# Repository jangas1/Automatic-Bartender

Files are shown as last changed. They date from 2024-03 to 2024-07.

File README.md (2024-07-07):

## Automatic Bartender

This is a project of an automated bartender with several functions which can be accessed from a menu on an LCD display. It is core function is to detect shot glasses and pour any drink (it has to be mannualy set by putting a tube into it) and count the number of shots poured on each position (it can be reseted at any time in menu postion "Drink counter"). The menu is operated using the encoder by turning it and pressing it at a given position. It has 3 submenues: "Capacity", "Drink counter" and "Pour" (which isn't really a submenu, but a button). "Capacity" submenu lets the user change the capacity of their drinks (with 5 ml step). "Drink counter" counts drink on each position and can reset the counter at any moment. "Pour" starts the automatic bartender and pours drinks on each position.

# Example of its work

<video width="640" height="480" controls>
  <source src="AutomaticBartenderExample.mp4" type="video/mp4">
</video>

If the video of its work is unavailable or doesn't work, use this [link](AutomaticBartenderExample.mp4)

Created by:
Mateusz Jangas
Daniel Niewiadomski

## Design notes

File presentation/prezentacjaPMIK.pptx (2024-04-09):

## Stacja Barmańska

Daniel Niewiadomski i Mateusz Jangas

## Zastosowanie urządzenia/algorytm działania

- Połóż dedykowane dla urządzenia kieliszki na od 1 do 4 dowolnych pozycji
- (opcjonalne) połóż szklanki i ustaw poprzez stronę internetową na których pozycjach się znajdują
- Program zapala diodę gdy dana pozycja jest aktywna
- Ustaw encoderem w menu, znajdującym się na wyświetlaczu, ile mililitrów urządzenie ma polewać
- Uruchom polewanie dowolnego napoju podłączonego do urządzenia
- Ciesz się resztą wieczoru obserwując w menu jaka ilość drinków została polana na każdej pozycji

## Stopień zaawansowania - mechanika

(tu wklej ss z inventora)

## Napotkane problemy i ich rozwiązania

- (Tu Daniel coś wstawia)

## Stopień zaawansowania - oprogramowanie

Designed by PoweredTemplate.com

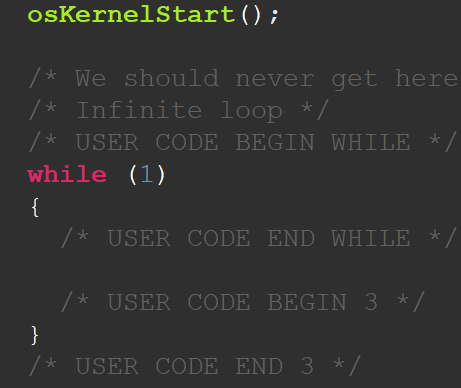
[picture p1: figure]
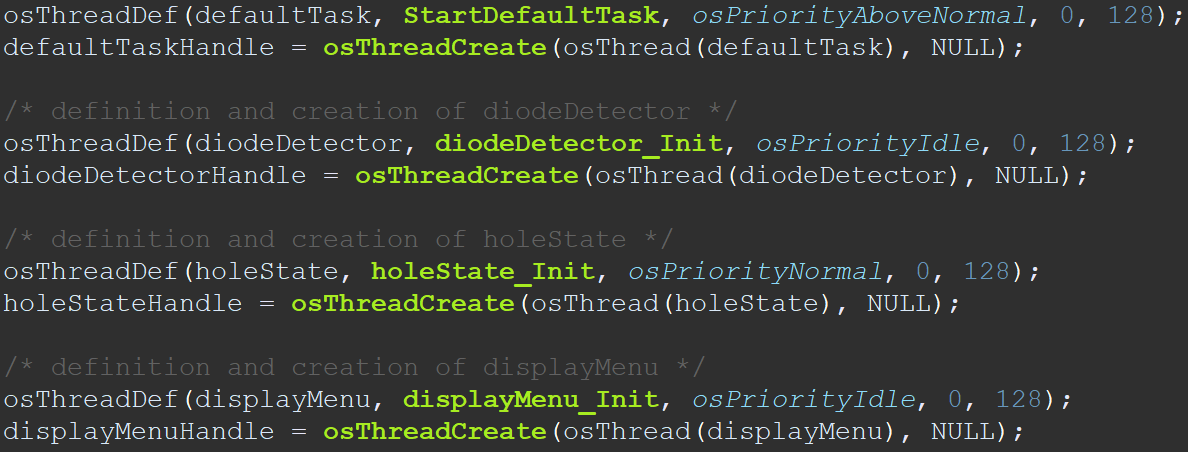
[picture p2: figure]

## Stopień zaawansowania - oprogramowanie

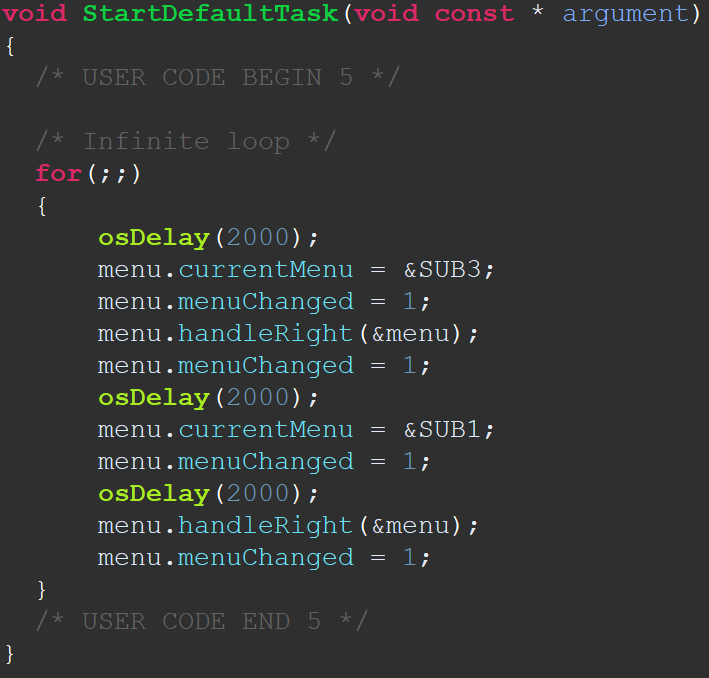
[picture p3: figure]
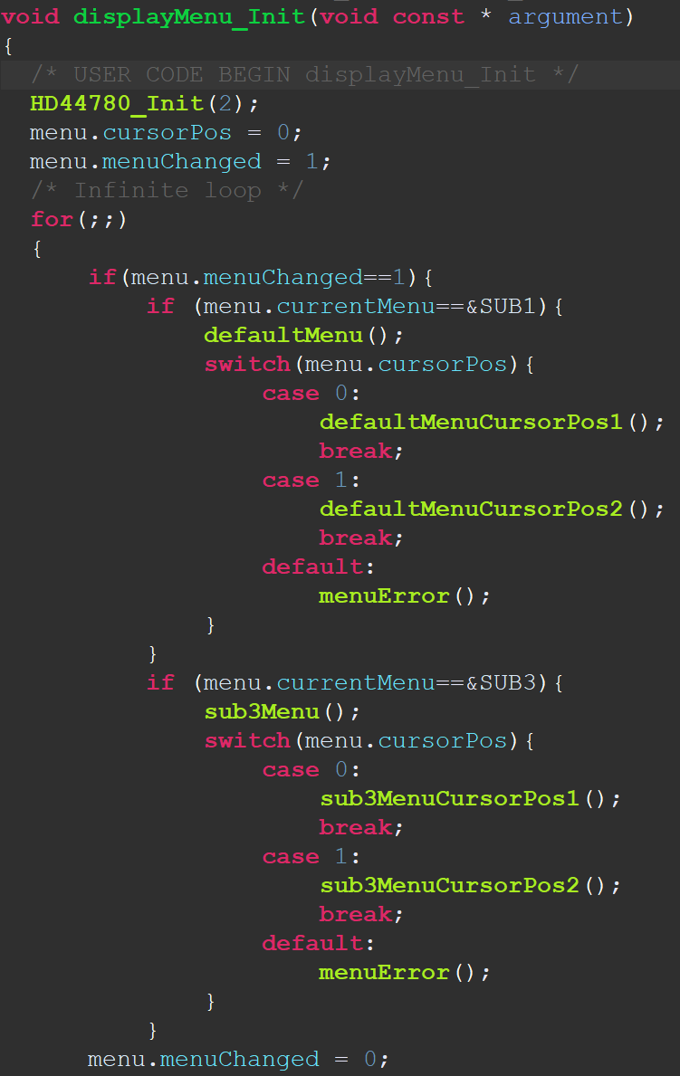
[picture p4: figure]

## Napotkane problemy i ich rozwiązania

- Zbyt lekkie kieliszki – problem z zastosowaniem tensorów czy przycisków do automatycznego wykrywania

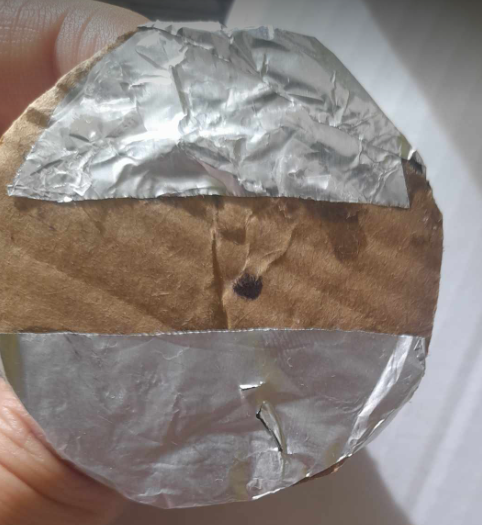
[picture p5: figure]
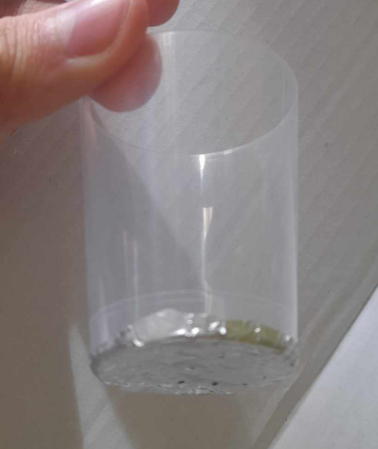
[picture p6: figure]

## Koniec

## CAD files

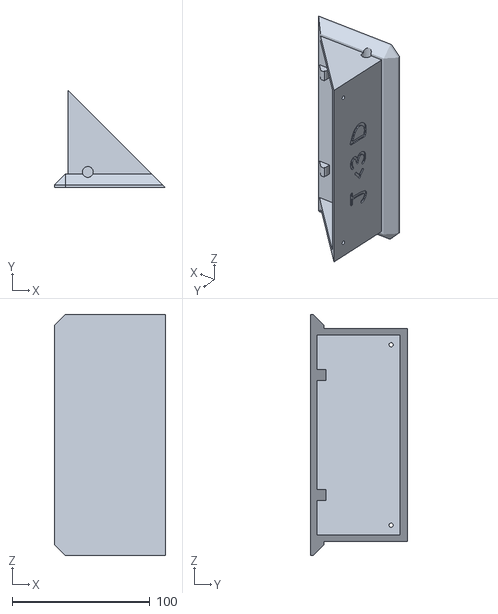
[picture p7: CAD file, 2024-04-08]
mechanical/manuDisplayHolder.stl
80.7 x 70.7 x 175.0

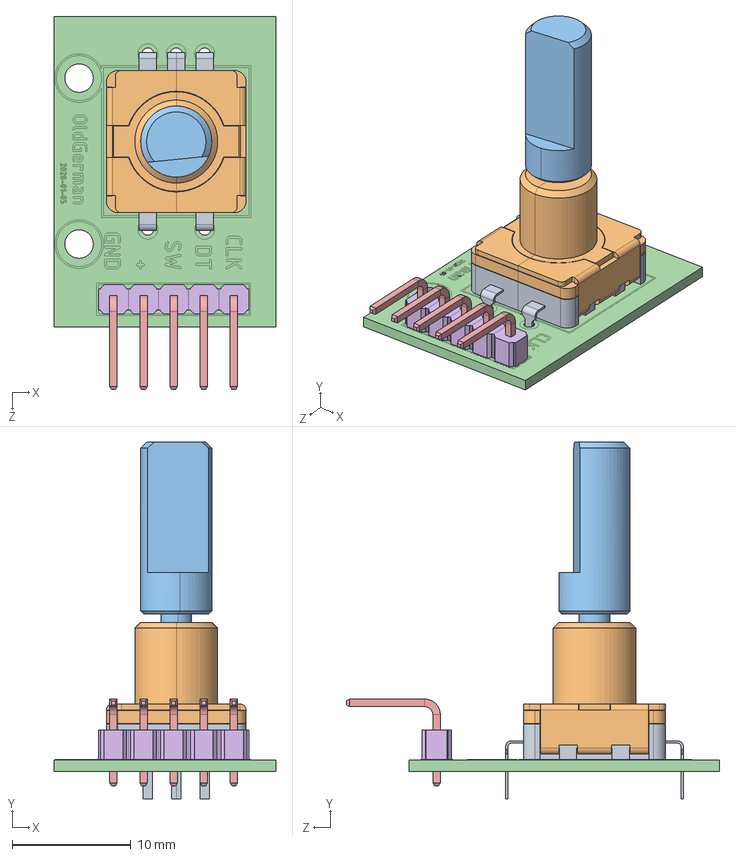
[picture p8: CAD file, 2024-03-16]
mechanical/STEPS/KY-040 Rotary Encoder.STEP
18.7 x 30.1 x 31.5 mm
Rotary Encoder
D-handle
pcb
2.54 5PIN 90

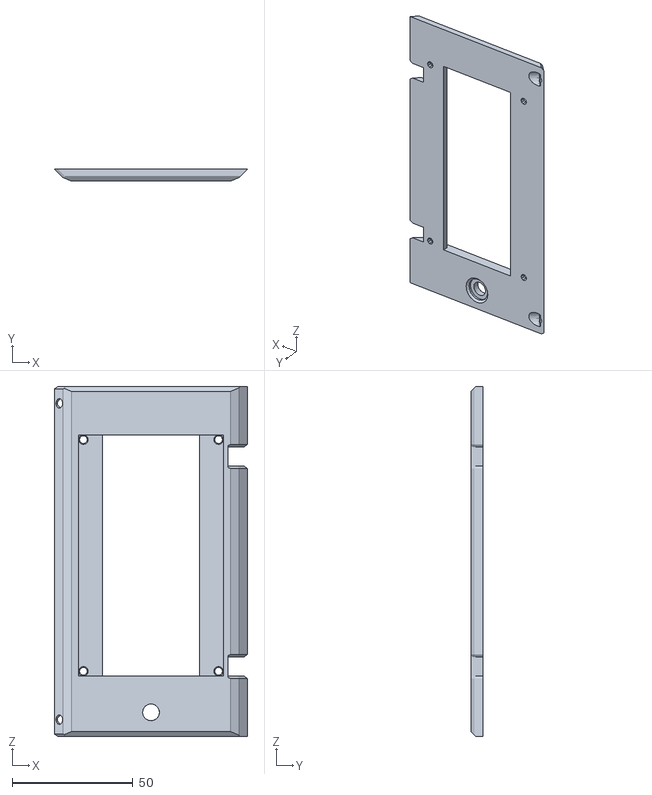
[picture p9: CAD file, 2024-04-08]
mechanical/menuDisplay.stl
80.0 x 5.00 x 145.0

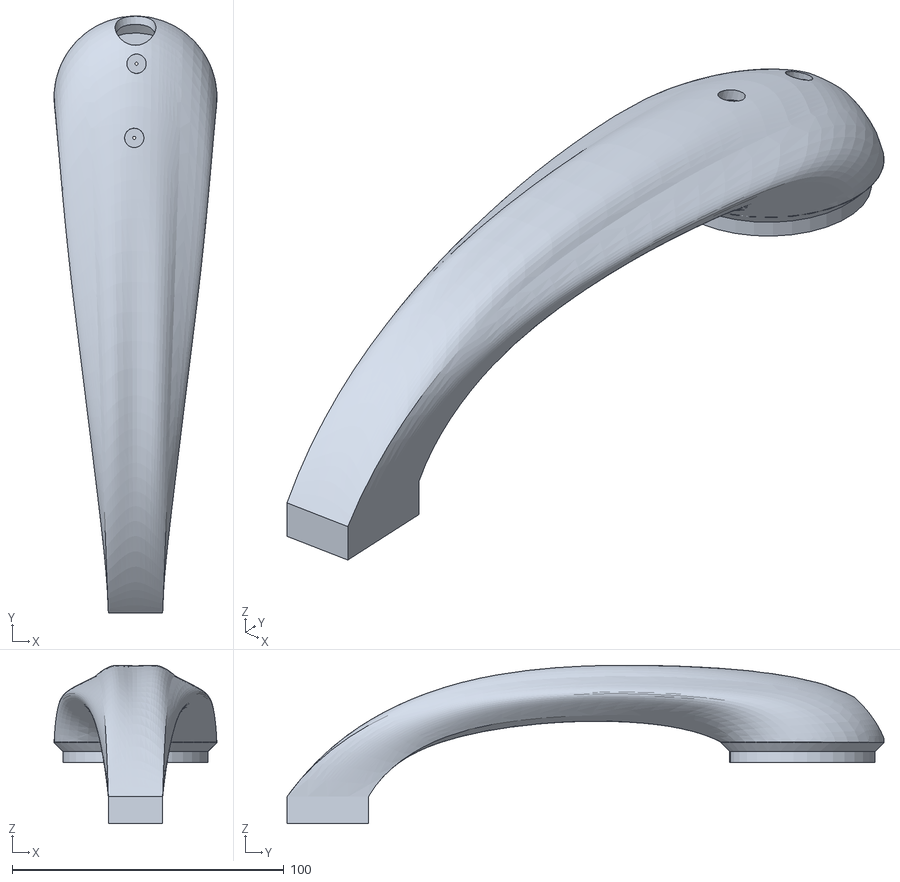
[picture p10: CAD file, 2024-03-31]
mechanical/Head.stl
60.0 x 219.7 x 58.3

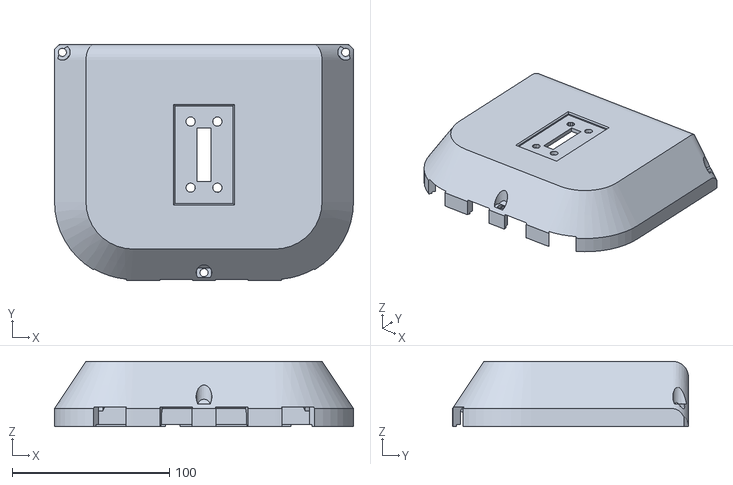
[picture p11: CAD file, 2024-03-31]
mechanical/Top.stl
190.0 x 150.0 x 41.5

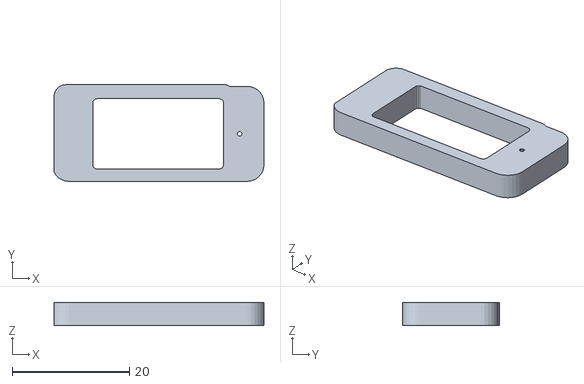
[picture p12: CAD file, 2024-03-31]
mechanical/ServoPlate.stl
35.8 x 16.5 x 4.00

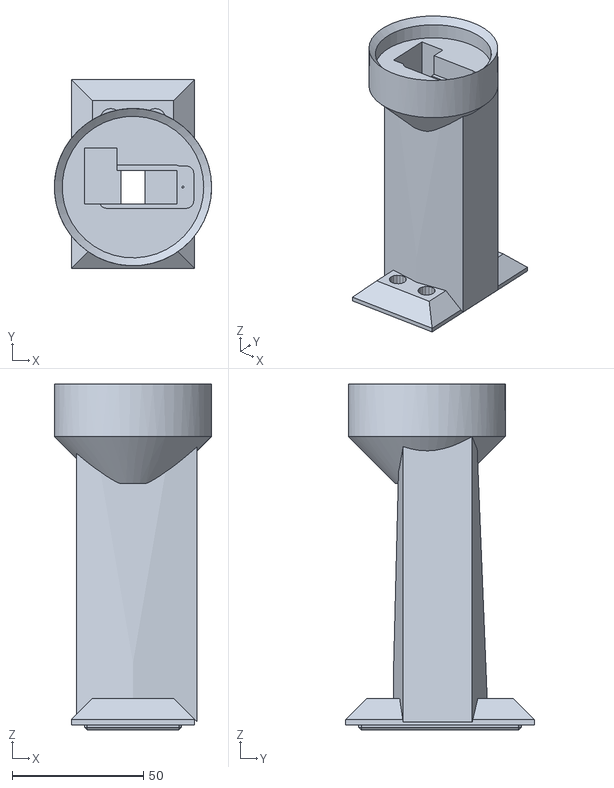
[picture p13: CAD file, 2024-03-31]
mechanical/TowerTrue.stl
60.0 x 72.0 x 132.0

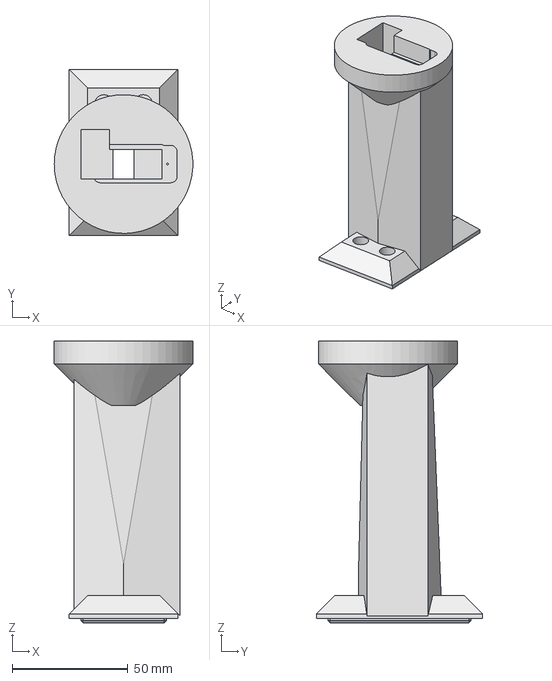
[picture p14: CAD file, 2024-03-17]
mechanical/Tower.stp
59.9 x 72.0 x 122.0 mm

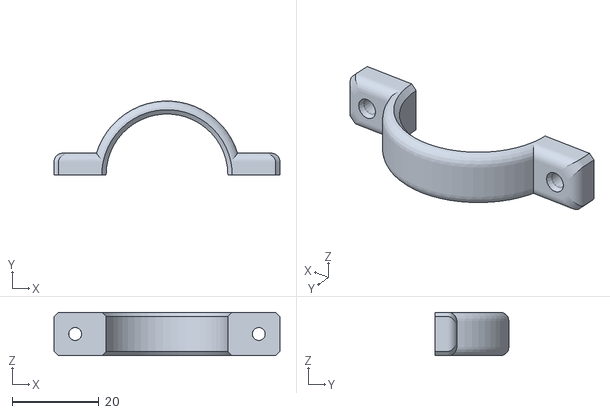
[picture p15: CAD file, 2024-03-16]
mechanical/PumpHolderTop.stl
52.0 x 17.0 x 10.0

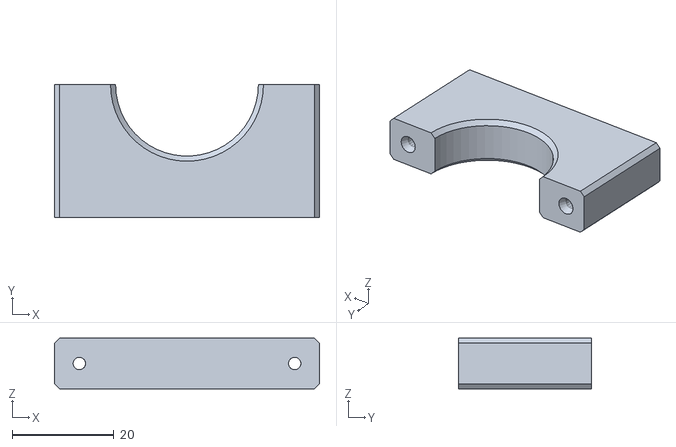
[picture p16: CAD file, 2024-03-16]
mechanical/PumpHolderBot.stl
52.0 x 26.0 x 10.0

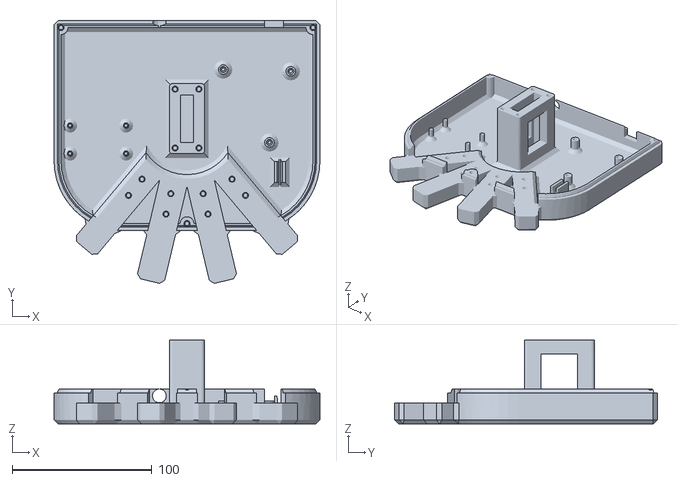
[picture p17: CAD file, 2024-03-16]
mechanical/bottom.stl
190.0 x 187.7 x 60.0

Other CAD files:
mechanical/Część1.ipt
mechanical/Head.ipt
mechanical/Pump.ipt
mechanical/PumpHolder.ipt
mechanical/PumpHolderBot.ipt
mechanical/PumpHolderTop.ipt
mechanical/STEPS/2.54 5PIN 90.ipt
mechanical/STEPS/D-handle.ipt
mechanical/STEPS/Jumper 1.ipt
mechanical/STEPS/KY-040 Rotary Encoder.iam
mechanical/STEPS/L3.ipt
mechanical/STEPS/LM2596 DC to DC Buck Converter 3 A.iam
mechanical/STEPS/LM2596S.ipt
mechanical/STEPS/MB1136 rev C.ipt
mechanical/STEPS/NUCLEO-F091RC.iam
mechanical/STEPS/OldVersions/SG90 - Micro Servo 9g - Tower Pro.0002.iam
mechanical/STEPS/Rotary Encoder.ipt
mechanical/STEPS/SG90 - Micro Servo 9g - Tower Pro.1_Pea.ipt
mechanical/STEPS/SG90 - Micro Servo 9g - Tower Pro.2_Pea.ipt
mechanical/STEPS/SG90 - Micro Servo 9g - Tower Pro.3_Pea.ipt
mechanical/STEPS/SG90 - Micro Servo 9g - Tower Pro.4_Pea.ipt
mechanical/STEPS/SG90 - Micro Servo 9g - Tower Pro.iam
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

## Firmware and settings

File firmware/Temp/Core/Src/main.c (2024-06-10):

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
/* Includes ------------------------------------------------------------------*/
#include "main.h"
#include "cmsis_os.h"

/* USER CODE BEGIN Includes */
#include "menuHandler.h"
#include "shotHolder.h"
#include "liquidcrystal_i2c.h"
#include "servo.h"
#include "encoder.h"
/* USER CODE END Includes */

I2C_HandleTypeDef hi2c1;

TIM_HandleTypeDef htim2;
TIM_HandleTypeDef htim9;

osThreadId defaultTaskHandle;
osThreadId diodeDetectorHandle;
osThreadId holeStateHandle;
osThreadId displayMenuHandle;
osThreadId servoPourHandle;
/* USER CODE BEGIN PV */
/* delete them later */
uint8_t holeState1 = 0;
uint8_t menuCursor = 0;
uint8_t subMenu = 0;

/**
 * @brief Assigns function names to each substructure and drink position structure
 *
 *  This allows to use "handleLeft", "handleRight" and "clickedReact" only for better clarity
 */
sub_t SUB1 = {.leftReact = leftReact1, .rightReact = rightReact1, .clickedReact=clickedReact1};
sub_t SUB2 = {.leftReact = leftReact2, .rightReact = rightReact2, .clickedReact=clickedReact2};
sub_t SUB3 = {.leftReact = leftReact3, .rightReact = rightReact3, .clickedReact=clickedReact3};
menu_t menu = {.handleLeft = handleLeft, .handleRight = handleRight, .clickedReact=handleClicked};
drinkpos_t drinkpos = {{0,0,0,0}, .drinkChange = drinkChange, .drinkReset = drinkReset};
/* USER CODE END PV */

void SystemClock_Config(void);
static void MX_GPIO_Init(void);
static void MX_I2C1_Init(void);
static void MX_TIM2_Init(void);
static void MX_TIM9_Init(void);
void StartDefaultTask(void const * argument);
void diodeDetector_Init(void const * argument);
void holeState_Init(void const * argument);
void displayMenu_Init(void const * argument);
void pourInit(void const * argument);

/* USER CODE BEGIN PFP */
/*

*/
/* USER CODE END PFP */

/**
  * @brief  The application entry point.
  * @retval int
  */
int main(void)
{
  /* USER CODE BEGIN 1 */
  menu.currentMenu = &SUB1;
  /* USER CODE END 1 */

  /* MCU Configuration--------------------------------------------------------*/

  /* Reset of all peripherals, Initializes the Flash interface and the Systick. */
  HAL_Init();

  /* Configure the system clock */
  SystemClock_Config();

  /* Initialize all configured peripherals */
  MX_GPIO_Init();
  MX_I2C1_Init();
  MX_TIM2_Init();
  MX_TIM9_Init();
  /* USER CODE BEGIN 2 */
  encoderInit();
  HAL_TIM_Base_Start_IT(&htim2);
  HAL_TIM_PWM_Start(&htim9, TIM_CHANNEL_1);
  initServo();
  /* USER CODE END 2 */

  /* USER CODE BEGIN RTOS_MUTEX */
  /* add mutexes, ... */
  /* USER CODE END RTOS_MUTEX */

  /* USER CODE BEGIN RTOS_SEMAPHORES */
  /* add semaphores, ... */
  /* USER CODE END RTOS_SEMAPHORES */

  /* USER CODE BEGIN RTOS_TIMERS */
  /* start timers, add new ones, ... */
  /* USER CODE END RTOS_TIMERS */

  /* USER CODE BEGIN RTOS_QUEUES */
  /* add queues, ... */
  /* USER CODE END RTOS_QUEUES */

  /* Create the thread(s) */
  /* definition and creation of defaultTask */
  osThreadDef(defaultTask, StartDefaultTask, osPriorityAboveNormal, 0, 128);
  defaultTaskHandle = osThreadCreate(osThread(defaultTask), NULL);

  /* definition and creation of diodeDetector */
  osThreadDef(diodeDetector, diodeDetector_Init, osPriorityIdle, 0, 128);
  diodeDetectorHandle = osThreadCreate(osThread(diodeDetector), NULL);

  /* definition and creation of holeState */
  osThreadDef(holeState, holeState_Init, osPriorityNormal, 0, 128);
  holeStateHandle = osThreadCreate(osThread(holeState), NULL);

  /* definition and creation of displayMenu */
  osThreadDef(displayMenu, displayMenu_Init, osPriorityIdle, 0, 128);
  displayMenuHandle = osThreadCreate(osThread(displayMenu), NULL);

  /* definition and creation of servoPour */
  osThreadDef(servoPour, pourInit, osPriorityHigh, 0, 128);
  servoPourHandle = osThreadCreate(osThread(servoPour), NULL);

  /* USER CODE BEGIN RTOS_THREADS */
  /* add threads, ... */
  /* USER CODE END RTOS_THREADS */

  /* Start scheduler */
  osKernelStart();

  /* We should never get here as control is now taken by the scheduler */
  /* Infinite loop */
  /* USER CODE BEGIN WHILE */
  while (1)
  {
    /* USER CODE END WHILE */

    /* USER CODE BEGIN 3 */
  }
  /* USER CODE END 3 */
}

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
/* USER CODE BEGIN Header_StartDefaultTask */
/**
  * @brief  Function implementing the defaultTask thread.
  * @param  argument: Not used
  * @retval None
  */
/* USER CODE END Header_StartDefaultTask */
void StartDefaultTask(void const * argument)
{
  /* USER CODE BEGIN 5 */

  /* Infinite loop */
  for(;;)
  {

	  osDelay(10000);
  }
  /* USER CODE END 5 */
}

/* USER CODE BEGIN Header_diodeDetector_Init */
/**
* @brief Function implementing the diodeDetector thread.
*
* This thread is responsible for LED lightning when a shot glass is detected on holders positions
* @param argument: Not used
* @retval None
*/
/* USER CODE END Header_diodeDetector_Init */
void diodeDetector_Init(void const * argument)
{
  /* USER CODE BEGIN diodeDetector_Init */
  /* Infinite loop */
  for(;;)
  {

	if (drinkpos.postitionOfDrinks[0] == 1){
		HAL_GPIO_WritePin(diode1_GPIO_Port, diode1_Pin, 1);
	}
	else{
		HAL_GPIO_WritePin(diode1_GPIO_Port, diode1_Pin, 0);
	}
	if (drinkpos.postitionOfDrinks[1] == 1){
		HAL_GPIO_WritePin(diode2_GPIO_Port, diode2_Pin, 1);
	}
	else{
		HAL_GPIO_WritePin(diode2_GPIO_Port, diode2_Pin, 0);
	}
	if (drinkpos.postitionOfDrinks[2] == 1){
		HAL_GPIO_WritePin(diode3_GPIO_Port, diode3_Pin, 1);
	}
	else{
		HAL_GPIO_WritePin(diode3_GPIO_Port, diode3_Pin, 0);
	}
	if (drinkpos.postitionOfDrinks[3] == 1){
		HAL_GPIO_WritePin(diode4_GPIO_Port, diode4_Pin, 1);
	}
	else{
		HAL_GPIO_WritePin(diode4_GPIO_Port, diode4_Pin, 0);
	}

	osDelay(100);
  }
  /* USER CODE END diodeDetector_Init */
}

/* USER CODE BEGIN Header_holeState_Init */
/**
* @brief Function implementing the holeState thread.
*
* This thread is responsible for checking whether the glass is in position or has been removed from it
* @param argument: Not used
* @retval None
*/
/* USER CODE END Header_holeState_Init */
void holeState_Init(void const * argument)
{
  /* USER CODE BEGIN holeState_Init */
  /* Infinite loop */
  for(;;)
  {

	if (HAL_GPIO_ReadPin(holeStatePin1_GPIO_Port, holeStatePin1_Pin) == 0){
		drinkpos.drinkChange(&drinkpos, 1);
	}
	else{
		drinkpos.drinkChange(&drinkpos, 11);
	}

	if (HAL_GPIO_ReadPin(holeStatePin2_GPIO_Port, holeStatePin2_Pin) == 0){
		drinkpos.drinkChange(&drinkpos, 2);
	}
	else{
		drinkpos.drinkChange(&drinkpos, 22);
	}
	if (HAL_GPIO_ReadPin(holeStatePin3_GPIO_Port, holeStatePin3_Pin) == 0){
		drinkpos.drinkChange(&drinkpos, 3);
	}
	else{
		drinkpos.drinkChange(&drinkpos, 33);
	}
	if (HAL_GPIO_ReadPin(holeStatePin4_GPIO_Port, holeStatePin4_Pin) == 0){
		drinkpos.drinkChange(&drinkpos, 4);
	}
	else{
		drinkpos.drinkChange(&drinkpos, 44);
	}

    osDelay(100);
  }
  /* USER CODE END holeState_Init */
}

/* USER CODE BEGIN Header_displayMenu_Init */
/**
* @brief Function implementing the displayMenu thread.
*
* This thread is responsible for permanently displaying current menu and current cursor position
* @param argument: Not used
* @retval None
*/
/* USER CODE END Header_displayMenu_Init */
void displayMenu_Init(void const * argument)
{
  /* USER CODE BEGIN displayMenu_Init */
  HD44780_Init(2);
  drinkCounterReset();
  menu.subMenuFlag = 1;
  menu.cursorPos = 0;
  menu.menuChanged = 1;
  menu.mililiters = 10;
  /* Infinite loop */
  for(;;)
  {
	  switch(menu.subMenuFlag){
	  	  case 1:
	  		  menu.currentMenu = &SUB1;
	  		  break;
	  	  case 2:
	          menu.currentMenu = &SUB2;
	          break;
	  	  case 3:
	  		  menu.currentMenu = &SUB3;
	  		  break;
	  }
	  if(menu.menuChanged==1){
		  if (menu.currentMenu==&SUB1){
			  defaultMenu();
			  switch(menu.cursorPos){
			  	  case 0:
			  		  defaultMenuCursorPos1();
			  		  break;
			  	  case 1:
			  		  defaultMenuCursorPos2();
			  		  break;
			  	  case 2:
			  		  defaultMenuCursorPos3();
			  		  break;
			  }
		  }
		  if (menu.currentMenu==&SUB2){
			  sub2Menu(&menu);
			  switch(menu.cursorPos){
			  	  case 0:
			  		  sub2MenuCursorPos1();
			  		  break;
			  	  case 1:
			  		  sub2MenuCursorPos2();
			  		  break;
			  }
		  }
		  if (menu.currentMenu==&SUB3){
			  sub3Menu();
			  switch(menu.cursorPos){
			  	  case 0:
			  		  sub3MenuCursorPos1();
			  		  break;
			  	  case 1:
			  		  sub3MenuCursorPos2();
			  		  break;
			  }
		  }
	  menu.menuChanged = 0;
	  }
	osDelay(30);
  }
  /* USER CODE END displayMenu_Init */
}

/* USER CODE BEGIN Header_pourInit */

void pump(int timeOn){
	osDelay(2000);
	HAL_GPIO_WritePin(pump_GPIO_Port, pump_Pin, 1);
	osDelay(timeOn);
	HAL_GPIO_WritePin(pump_GPIO_Port, pump_Pin, 0);
	osDelay(2000);
}
/**
* @brief Function implementing the servoPour thread.
*
* This thread s responsible for adjusting servo to proper positions and pouring correct amount of drink
* @param argument: Not used
* @retval None
*/
/* USER CODE END Header_pourInit */
void pourInit(void const * argument)
{
  /* USER CODE BEGIN pourInit */
	menu.pourChanged = 0;
	HAL_GPIO_WritePin(pump_GPIO_Port, pump_Pin, 0);
  /* Infinite loop */
  for(;;)
  {
	if (menu.pourChanged == 1){
		setRotation(10);
		osDelay(1500);
		if (drinkpos.postitionOfDrinks[0] == 1){
			setRotation(58);
			pump(menu.mililiters*200);
			drinkAddCounter1();
		}
		if (drinkpos.postitionOfDrinks[1] == 1){
			setRotation(84);
			pump(menu.mililiters*200);
			drinkAddCounter2();
		}
		if (drinkpos.postitionOfDrinks[2] == 1){
			setRotation(112);
			pump(menu.mililiters*200);
			drinkAddCounter3();
		}
		if (drinkpos.postitionOfDrinks[3] == 1){
			setRotation(141);
			pump(menu.mililiters*200);
			drinkAddCounter4();
		}
		osDelay(500);
		setRotation(180);
		menu.pourChanged = 0;
	}
    osDelay(30);
  }
  /* USER CODE END pourInit */
}

/**
  * @brief  Period elapsed callback in non blocking mode
  * @note   This function is called  when TIM1 interrupt took place, inside
  * HAL_TIM_IRQHandler(). It makes a direct call to HAL_IncTick() to increment
  * a global variable "uwTick" used as application time base.
  * @param  htim : TIM handle
  * @retval None
  */
void HAL_TIM_PeriodElapsedCallback(TIM_HandleTypeDef *htim)
{
  if (htim->Instance == TIM1) {
    HAL_IncTick();
  }
}

/**
  * @brief  This function is executed in case of error occurrence.
  * @retval None
  */
void Error_Handler(void)
{
  /* USER CODE BEGIN Error_Handler_Debug */
  /* User can add his own implementation to report the HAL error return state */
  __disable_irq();
  while (1)
  {
  }
  /* USER CODE END Error_Handler_Debug */
}

#ifdef  USE_FULL_ASSERT
/**
  * @brief  Reports the name of the source file and the source line number
  *         where the assert_param error has occurred.
  * @param  file: pointer to the source file name
  * @param  line: assert_param error line source number
  * @retval None
  */
void assert_failed(uint8_t *file, uint32_t line)
{
  /* USER CODE BEGIN 6 */
  /* User can add his own implementation to report the file name and line number,
     ex: printf("Wrong parameters value: file %s on line %d\r\n", file, line) */
  /* USER CODE END 6 */
}
#endif /* USE_FULL_ASSERT */

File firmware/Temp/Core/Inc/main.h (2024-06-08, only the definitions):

#define CS_I2C_SPI_Pin GPIO_PIN_3
#define CS_I2C_SPI_GPIO_Port GPIOE
#define PC14_OSC32_IN_Pin GPIO_PIN_14
#define PC14_OSC32_IN_GPIO_Port GPIOC
#define PC15_OSC32_OUT_Pin GPIO_PIN_15
#define PC15_OSC32_OUT_GPIO_Port GPIOC
#define PH0_OSC_IN_Pin GPIO_PIN_0
#define PH0_OSC_IN_GPIO_Port GPIOH
#define PH1_OSC_OUT_Pin GPIO_PIN_1
#define PH1_OSC_OUT_GPIO_Port GPIOH
#define OTG_FS_PowerSwitchOn_Pin GPIO_PIN_0
#define OTG_FS_PowerSwitchOn_GPIO_Port GPIOC
#define holeStatePin1_Pin GPIO_PIN_1
#define holeStatePin1_GPIO_Port GPIOC
#define diode1_Pin GPIO_PIN_2
#define diode1_GPIO_Port GPIOC
#define PDM_OUT_Pin GPIO_PIN_3
#define PDM_OUT_GPIO_Port GPIOC
#define I2S3_WS_Pin GPIO_PIN_4
#define I2S3_WS_GPIO_Port GPIOA
#define SPI1_SCK_Pin GPIO_PIN_5
#define SPI1_SCK_GPIO_Port GPIOA
#define SPI1_MISO_Pin GPIO_PIN_6
#define SPI1_MISO_GPIO_Port GPIOA
#define SPI1_MOSI_Pin GPIO_PIN_7
#define SPI1_MOSI_GPIO_Port GPIOA
#define diode2_Pin GPIO_PIN_4
#define diode2_GPIO_Port GPIOC
#define holeStatePin2_Pin GPIO_PIN_5
#define holeStatePin2_GPIO_Port GPIOC
#define diode3_Pin GPIO_PIN_0
#define diode3_GPIO_Port GPIOB
#define holeStatePin3_Pin GPIO_PIN_1
#define holeStatePin3_GPIO_Port GPIOB
#define diode4_Pin GPIO_PIN_2
#define diode4_GPIO_Port GPIOB
#define holeStatePin4_Pin GPIO_PIN_7
#define holeStatePin4_GPIO_Port GPIOE
#define pump_Pin GPIO_PIN_8
#define pump_GPIO_Port GPIOE
#define CLK_IN_Pin GPIO_PIN_10
#define CLK_IN_GPIO_Port GPIOB
#define LD4_Pin GPIO_PIN_12
#define LD4_GPIO_Port GPIOD
#define LD3_Pin GPIO_PIN_13
#define LD3_GPIO_Port GPIOD
#define LD5_Pin GPIO_PIN_14
#define LD5_GPIO_Port GPIOD
#define LD6_Pin GPIO_PIN_15
#define LD6_GPIO_Port GPIOD
#define I2S3_MCK_Pin GPIO_PIN_7
#define I2S3_MCK_GPIO_Port GPIOC
#define VBUS_FS_Pin GPIO_PIN_9
#define VBUS_FS_GPIO_Port GPIOA
#define OTG_FS_ID_Pin GPIO_PIN_10
#define OTG_FS_ID_GPIO_Port GPIOA
#define OTG_FS_DM_Pin GPIO_PIN_11
#define OTG_FS_DM_GPIO_Port GPIOA
#define OTG_FS_DP_Pin GPIO_PIN_12
#define OTG_FS_DP_GPIO_Port GPIOA
#define SWDIO_Pin GPIO_PIN_13
#define SWDIO_GPIO_Port GPIOA
#define SWCLK_Pin GPIO_PIN_14
#define SWCLK_GPIO_Port GPIOA
#define I2S3_SCK_Pin GPIO_PIN_10
#define I2S3_SCK_GPIO_Port GPIOC
#define I2S3_SD_Pin GPIO_PIN_12
#define I2S3_SD_GPIO_Port GPIOC
#define Audio_RST_Pin GPIO_PIN_4
#define Audio_RST_GPIO_Port GPIOD
#define OTG_FS_OverCurrent_Pin GPIO_PIN_5
#define OTG_FS_OverCurrent_GPIO_Port GPIOD
#define SWO_Pin GPIO_PIN_3
#define SWO_GPIO_Port GPIOB
#define enc_CLICK_Pin GPIO_PIN_4
#define enc_CLICK_GPIO_Port GPIOB
#define enc_DATA_Pin GPIO_PIN_5
#define enc_DATA_GPIO_Port GPIOB
#define enc_CLK_Pin GPIO_PIN_6
#define enc_CLK_GPIO_Port GPIOB
#define MEMS_INT2_Pin GPIO_PIN_1
#define MEMS_INT2_GPIO_Port GPIOE

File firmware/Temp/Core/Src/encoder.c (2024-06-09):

/**
 * @file encoder.c
 * @brief Implementation file for the encoder module.
 *
 * This file contains the implementation of the functions declared in encoder.h.
 *
 * Created on: May 10, 2024
 * Author: Daniel
 */

#include "encoder.h"

/**
 * @brief Global encoder instance.
 */
encoder enc;

extern menu_t menu;

/**
 * @brief Reacts to a left turn of the encoder.
 *
 * This function is called when the encoder is turned left. It handles the left turn event.
 */
void LeftReact(){
    menu.handleLeft(&menu);
}

/**
 * @brief Reacts to a right turn of the encoder.
 *
 * This function is called when the encoder is turned right. It handles the right turn event.
 */
void RightReact(){
    menu.handleRight(&menu);
}

/**
 * @brief Reacts to a click of the encoder button.
 *
 * This function is called when the encoder button is clicked. It handles the click event.
 */
void ClickedReact(){
    menu.clickedReact(&menu);
}

/**
 * @brief Interrupt Service Routine for the encoder.
 *
 * This function is called in response to changes in the encoder's signals.
 * It updates the encoder state and calls the appropriate callback functions.
 */
void ISR(){
    enc.lastClock = enc.newClock;
    enc.lastDir = enc.direction;
    enc.lastClicked = enc.Clicked;
    enc.newClock = HAL_GPIO_ReadPin(enc_CLK_GPIO_Port, enc_CLK_Pin);
    enc.direction = HAL_GPIO_ReadPin(enc_DATA_GPIO_Port, enc_DATA_Pin);
    enc.Clicked = !HAL_GPIO_ReadPin(enc_CLICK_GPIO_Port, enc_CLICK_Pin);

    if (((enc.lastClock != enc.newClock) && enc.newClock == 1)) {
        if (enc.direction == 1) {
            enc.LeftCallback();
        }
    } else if ((enc.lastDir != enc.direction) && enc.direction == 1) {
        if (enc.newClock == 1) {
            enc.RightCallback();
        }
    }
    if ((enc.Clicked == 1) && (enc.lastClicked == 0)) {
        enc.ClickedCallback();
    }
}

/**
 * @brief Initializes the encoder.
 *
 * This function initializes the encoder structure and sets the default callback functions.
 */
void encoderInit(){
    enc.ISR = ISR;
    enc.RightCallback = RightReact;
    enc.LeftCallback = LeftReact;
    enc.ClickedCallback = ClickedReact;
    enc.direction = 1;
    enc.lastClock = 1;
    enc.lastDir = 1;
    enc.newClock = 1;
}

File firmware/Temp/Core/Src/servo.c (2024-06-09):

/**
 * @file servo.c
 * @brief Implementation file for the servo module.
 *
 * This file contains the implementation of the functions declared in servo.h.
 */

#include "servo.h"
#include <math.h>

/**
 * @brief Global servo instance.
 *
 * Initialized with default values and function pointers.
 */
servo_t servo = {.rotation=0, .setRotation=setRotation, .initServo=initServo};

/**
 * @brief Converts degrees to raw servo position.
 *
 * This function maps the degrees (0 to 180) to the corresponding raw position
 * for the servo (HOME_RAW_POS to MAX_RAW_POS).
 *
 * @param degrees The desired rotation in degrees.
 * @return The corresponding raw position.
 */
unsigned int degreeToRaw(double degrees){
    return round(map_range(degrees, 0.0, 180.0, 90.0, 451.0));
}

/**
 * @brief Sets the servo rotation to the desired degrees.
 *
 * This function converts the desired degrees to the raw position and updates
 * the servo's position.
 *
 * @param desiredDegrees The desired rotation in degrees.
 */
void setRotation(int desiredDegrees){
    servo.rawPos = degreeToRaw(desiredDegrees);
    servo.rotation = desiredDegrees;
    TIM9->CCR1 = servo.rawPos;
}

/**
 * @brief Initializes the servo to the home position.
 *
 * This function sets the servo to the home position (90 degrees) and updates
 * the raw position.
 */
void initServo(){
    servo.rawPos = degreeToRaw(90);
    servo.rotation = 90;
    TIM9->CCR1 = servo.rawPos;
}

/**
 * @brief Maps a value from one range to another.
 *
 * This function maps a value from the old range (old_min to old_max) to the new range
 * (new_min to new_max).
 *
 * @param value The value to be mapped.
 * @param old_min The minimum value of the original range.
 * @param old_max The maximum value of the original range.
 * @param new_min The minimum value of the new range.
 * @param new_max The maximum value of the new range.
 * @return The mapped value in the new range.
 */
double map_range(double value, double old_min, double old_max, double new_min, double new_max) {
    return ((value - old_min) / (old_max - old_min)) * (new_max - new_min) + new_min;
}

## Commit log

2024-03-07 Main body shape
    [main_body.0002.ipt, main_body.ipt]
2024-03-08 gitignore setup
    [CUBE Debug.cfg]
2024-03-08 Deleted debug cfg
    [CUBE Debug.cfg]
2024-03-09 Modeling work
    [Body.ipt, Jumper 1.ipt, L3.ipt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]
2024-03-09 two new threads added (working sensor with diodes) + its mechanical prototype
    [Temporary Debug.cfg]
2024-03-10 Implemented encoder task. added board schematics
    [Connectors.SchDoc, MB1136.PcbDoc, MB1136.PrjPCB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]
2024-03-10 Encoder debounce mesurements
2024-03-12 Mechanical rework
    [2.54 5PIN 90.ipt, Body.ipt, D-handle.ipt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]
2024-03-12 Top part WIP
    [Top.ipt, bottom.ipt, mainASM.iam]
2024-03-13 Top work and arm begining
    [Top.ipt, Tower.ipt, mainASM.iam]
2024-03-13 Pump holders
    [Część1.ipt, PumpHolder.ipt, PumpHolderBot.ipt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]
2024-03-16 working display with menu and arrow pointer changing iwht encoder status change
    [configForTemp.txt]
2024-03-17 Tower part fin
    [SG90 - Micro Servo 9g - Tower Pro.0001.iam, SG90 - Micro Servo 9g - Tower Pro.iam, Tower.ipt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]
2024-03-23 Added missing? top holes
    [ServoPlate.ipt, ServoPlate.stl, Top.stl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]
2024-03-25 Kranik (Head)
    [Head.ipt, SG90 - Micro Servo 9g - Tower Pro.0001.iam, SG90 - Micro Servo 9g - Tower Pro.0002.iam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]
2024-03-25 Usunieto sruby
    [Head.ipt, Head.stl, mainASM.iam]
2024-04-01 added mechanical holder for LCD display and enocder
    [manuDisplayHolder.ipt, menuDisplay.ipt]
2024-04-06 quick mechanical fix + early stage of presentation
    [manuDisplayHolder.ipt, menuDisplay.ipt]
2024-04-06 added holes for assebly
    [menuDisplayAssembly.iam]
2024-04-08 Mechanical display holder fix
    [ScreenHolderASM.iam, manuDisplayHolder.ipt, manuDisplayHolder.stl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]
2024-04-10 Servo drivers
2024-05-10 Beter servo interface
2024-05-19 Final Encoder code
2024-05-22 shotHolder - mechanical
    [shotHolder.ipt]
2024-05-29 shotHolder struct with RTOS threads for detection
2024-05-30 mechanical fix
    [shotHolder.ipt]
2024-05-30 combined almost everything
    [configForTemp.txt]
2024-07-07 last update with markdown documentation
    [Connectors.SchDoc, MB1136.PcbDoc, MB1136.PrjPCB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]
2024-08-06 rename folders for better clarity
    [Temporary Debug.cfg]

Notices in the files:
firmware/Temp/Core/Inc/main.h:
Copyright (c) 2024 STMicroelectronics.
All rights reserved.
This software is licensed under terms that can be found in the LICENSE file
